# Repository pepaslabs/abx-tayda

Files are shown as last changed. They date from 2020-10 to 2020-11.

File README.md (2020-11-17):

# abx-tayda

A relay board for performing blind A/B testing of two audio sources.

This version of the board is designed around parts available from [Tayda electronics](https://www.taydaelectronics.com/).

See the thread at [diyaudio.com](https://www.diyaudio.com/forums/equipment-and-tools/361743-abx-box.html).

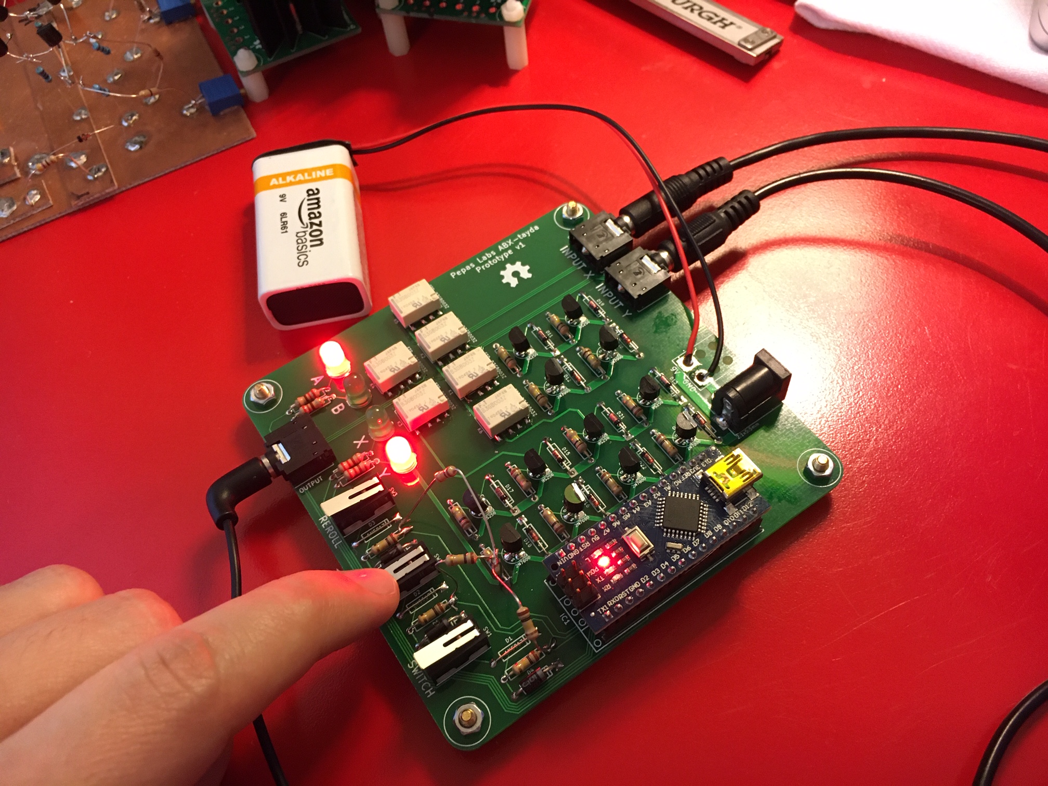
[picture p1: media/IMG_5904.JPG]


This board design is open source hardware, released under the terms of the [MIT license](https://opensource.org/licenses/MIT).  It requires an [ancient version of Kicad](https://archive.org/details/2013-kicad) (sorry, not sorry 😝).  Debian users will need to add a jessie source to install the libpng12 dependency.

## v4.1 release

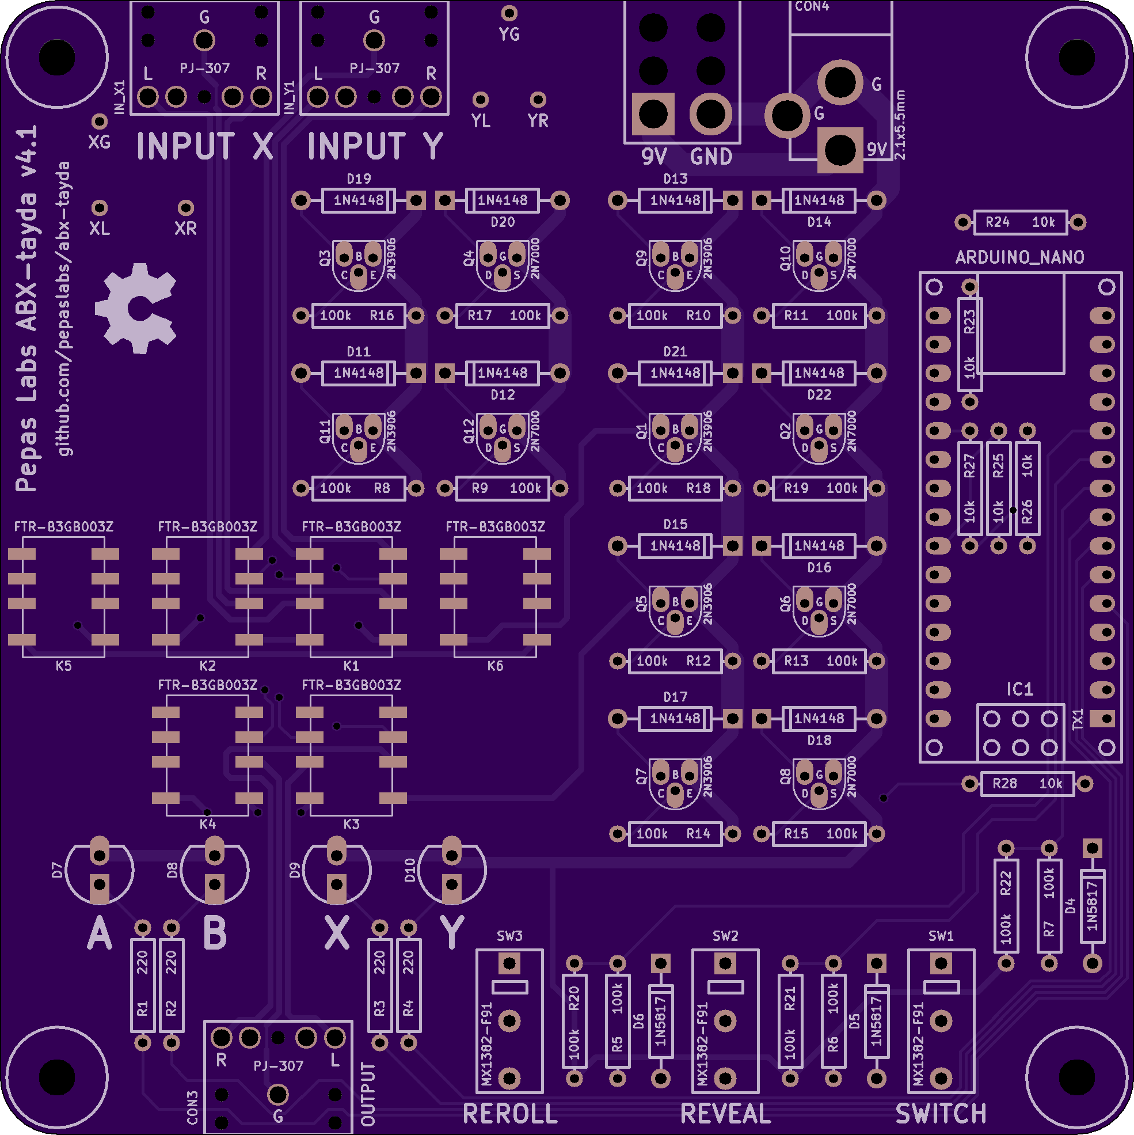
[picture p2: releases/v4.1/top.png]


[schematic](releases/v4.1/abx.pdf)

[gerbers.zip](releases/v4.1/gerbers.zip)

[firmware](https://github.com/pepaslabs/abx-tayda/blob/main/releases/v4.1/firmware/abx/abx.ino)

Changes from v4:
- Include missing base resistor R28.

### Bill of materials

- **D4-6**: three 1N5817 Schottky diodes.
  - Any diode will work, but the lower voltage drop of Schottky diodes extracts more useful life from the 9V battery.
  - [Tayda](https://www.taydaelectronics.com/1n5817-diode-schottky-1a-20v.html)
- **D7-10**: four LED's.
  - Any color.  3mm or 5mm.
  - [Tayda](https://www.taydaelectronics.com/leds/round-leds/5mm-leds/led-5mm-red.html)
- **D11-22**: twelve 1N4148 diodes.
  - Flyback diodes.  Any diode will work here.
  - [Tayda](https://www.taydaelectronics.com/1n4148-switching-signal-diode.html)
- **R1-4**: four 220R 1/4 watt resistors.
  - LED current limiting.  Tune the resistance value to get the LED brightness you prefer.
  - [Tayda](https://www.taydaelectronics.com/resistors/1-4w-metal-film-resistors/resistor-220-ohm-1-4w-1-metal-film-pkg-of-10.html)
- **R5-7,20-22**: six 100k 1/4 watt resistors.
  - Voltage dividers for Arduino inputs.  5% carbon film or 1% metal film.
  - [Tayda](https://www.taydaelectronics.com/resistors/1-4w-metal-film-resistors/10-x-resistor-100k-ohm-1-4w-1-metal-film-pkg-of-10.html)
- **R8-19**: twelve 100k 1/4 watt resistors.
  - MOSFET gate pull-up and pull-down resistors.  5% carbon film or 1% metal film.
  - [Tayda](https://www.taydaelectronics.com/resistors/1-4w-metal-film-resistors/10-x-resistor-100k-ohm-1-4w-1-metal-film-pkg-of-10.html)
- **R23-27**: six 10k 1/4 watt resistors.
  - PNP base current-limiting resistors.  5% carbon film or 1% metal film.
  - [Tayda](https://www.taydaelectronics.com/resistors/1-4w-metal-film-resistors/10-x-resistor-10k-ohm-1-4w-1-metal-film-pkg-of-10.html)
- **SW1-3**: three miniature micro switches.
  - Tayda [MX1382-F91](https://www.taydaelectronics.com/mx1382-f91-micro-switch-1p2t-1a-mx1382-f91.html)
- **Q1,3,5,7,9,11**: six 2N3906 PNP BJT transistors.
  - [Tayda](https://www.taydaelectronics.com/2n3906-general-propose-pnp-transistor.html)
  - Any TO-92 PNP transistor which can handle 100mA (with an EBC pinout) will work fine.
- **Q2,4,6,8,10,12**: six 2N7000 N-channel MOSFETs.
  - [Tayda](https://www.taydaelectronics.com/2n7000-mosfet-n-channel-60v-0-2a.html)
  - Any TO-92 N-channel MOSFET which can handle 100mA (with an SGD pinout) will work fine.
- **K1-6**: six 3V latching relays
  - Tayda [FTR-B3GB003Z](https://www.taydaelectronics.com/ftr-b3gb003z-b10-mini-relay-dpdt-3vdc-1a.html)
- **CON1-3**: three 3.5mm headphone jacks
  - Tayda [PJ-307](https://www.taydaelectronics.com/3-5mm-stereo-enclosed-socket-chassis-jack.html)
  - Digikey [SJ1-3523N](https://www.digikey.com/en/products/detail/cui-devices/SJ1-3523N/738689)
- **IC1**: one Arduino Nano board.
  - Any $5 Arduino Nano board on ebay will work fine.

Choose one:
- **CON4**: 2.1x5.5mm DC barrel jack
  - [Tayda](https://www.taydaelectronics.com/dc-power-jack-2-1mm-barrel-type-pcb-mount.html)
  - [Tayda](https://www.taydaelectronics.com/9v-9-volt-battery-clip-connector-with-barrel-jack-plug.html)
  - [Tayda](https://www.taydaelectronics.com/9v-battery-holder-with-barrel-jack-plug.html)
- **P1**: 9V battery pigtail

## v4 release

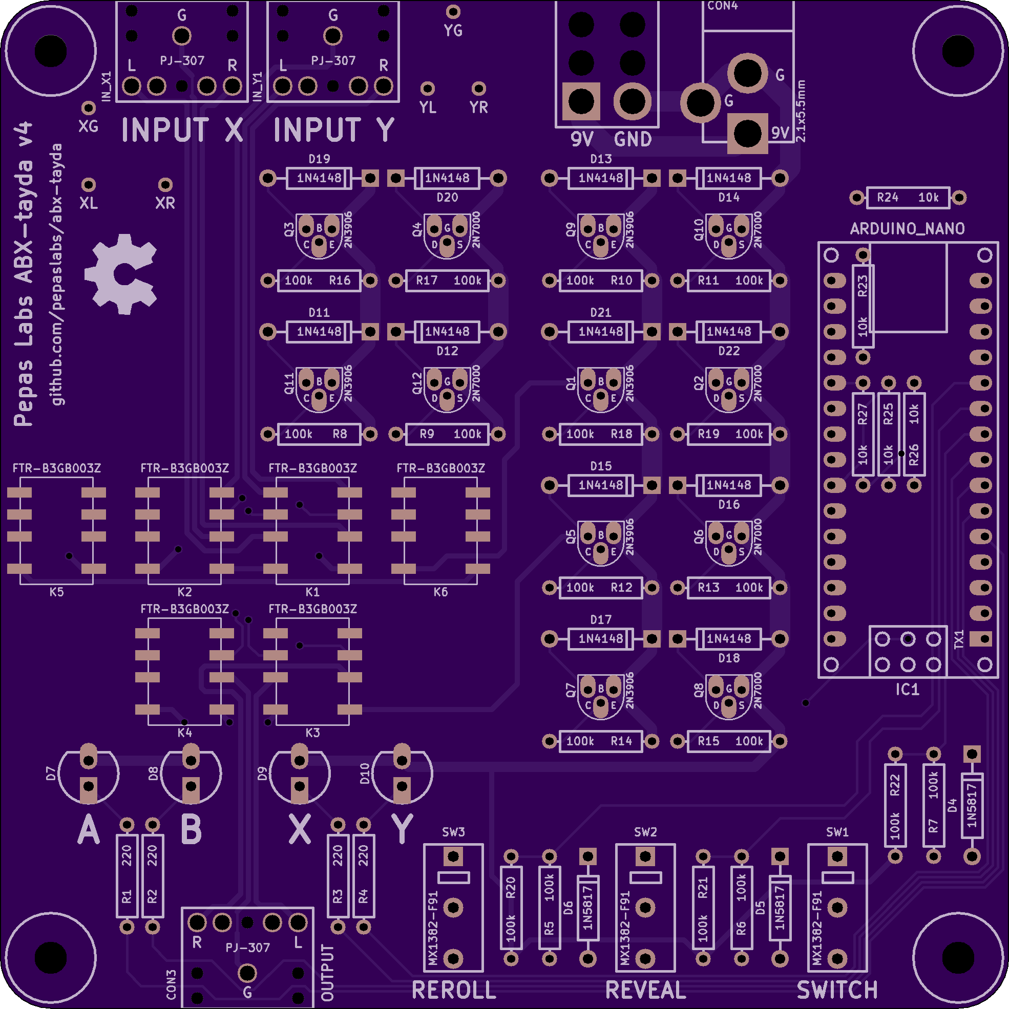
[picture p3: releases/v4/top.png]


[schematic](releases/v4/abx.pdf)

[gerbers.zip](releases/v4/gerbers.zip)

[firmware](https://github.com/pepaslabs/abx-tayda/blob/main/releases/v4/firmware/abx/abx.ino)

Changes from v3:
- Use 2N3906 PNP BJT's which are cheaper than BS250 P-channel MOSFETs (and are available from tayda)
- Use wider traces for the signal path.

## v3 release

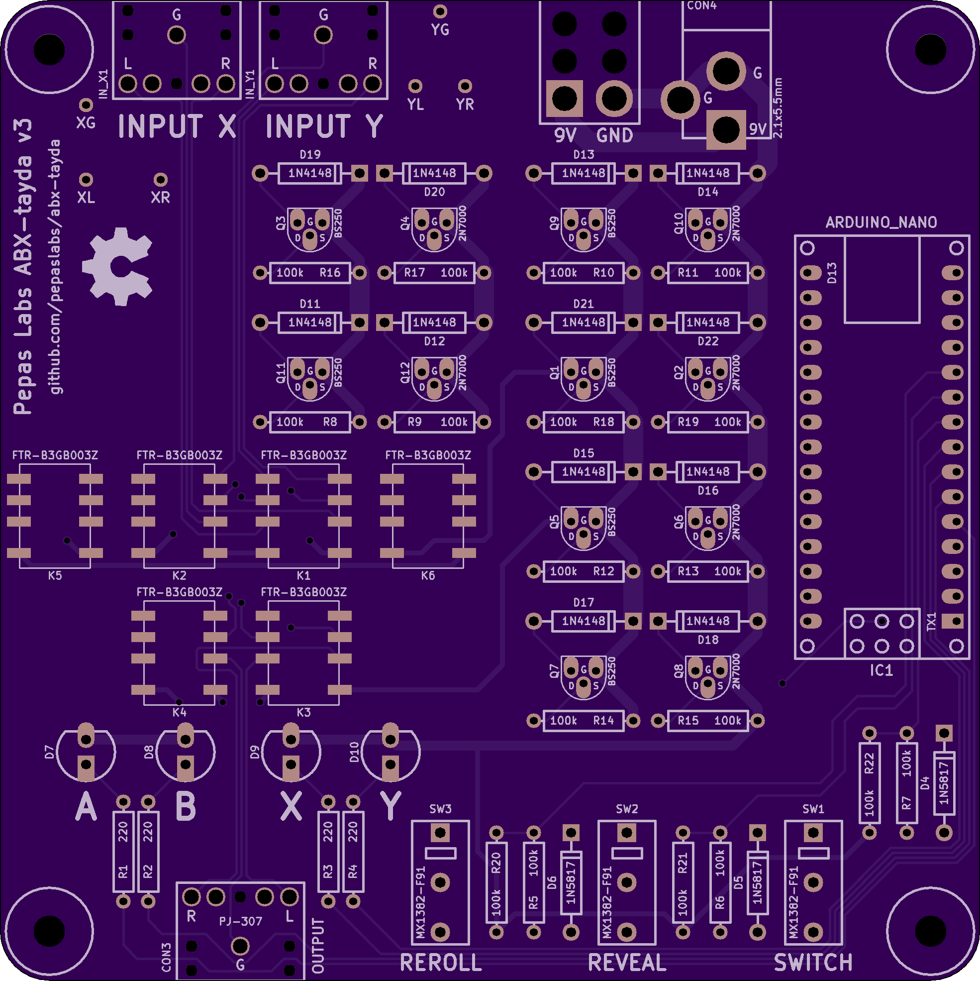
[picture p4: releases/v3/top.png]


[schematic](releases/v3/abx.pdf)

[gerbers.zip](releases/v3/gerbers.zip)

[firmware](https://github.com/pepaslabs/abx-tayda/blob/main/releases/v3/firmware/abx/abx.ino)

Changes from v2:
- Add test points to input X and Y for volume matching convenience.
- Use pins RX0, TX1 instead of A6, A7 (which cannot be used a digital outputs).

## v2 release

This release fixes a couple of bugs from v1:
- Replaced the 100k input resistors with proper voltage dividers.
- Fixed the silkscreen outline of the relays.

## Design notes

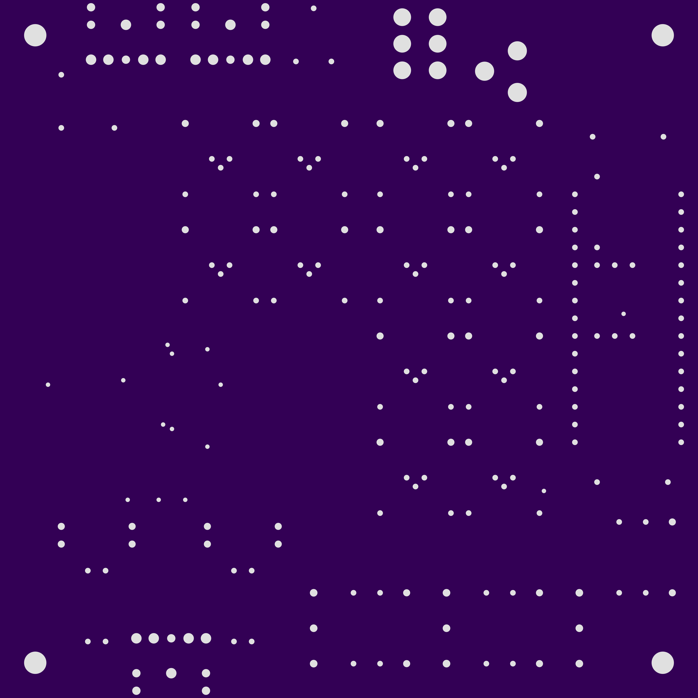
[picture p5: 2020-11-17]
releases/v4.1/drills.png

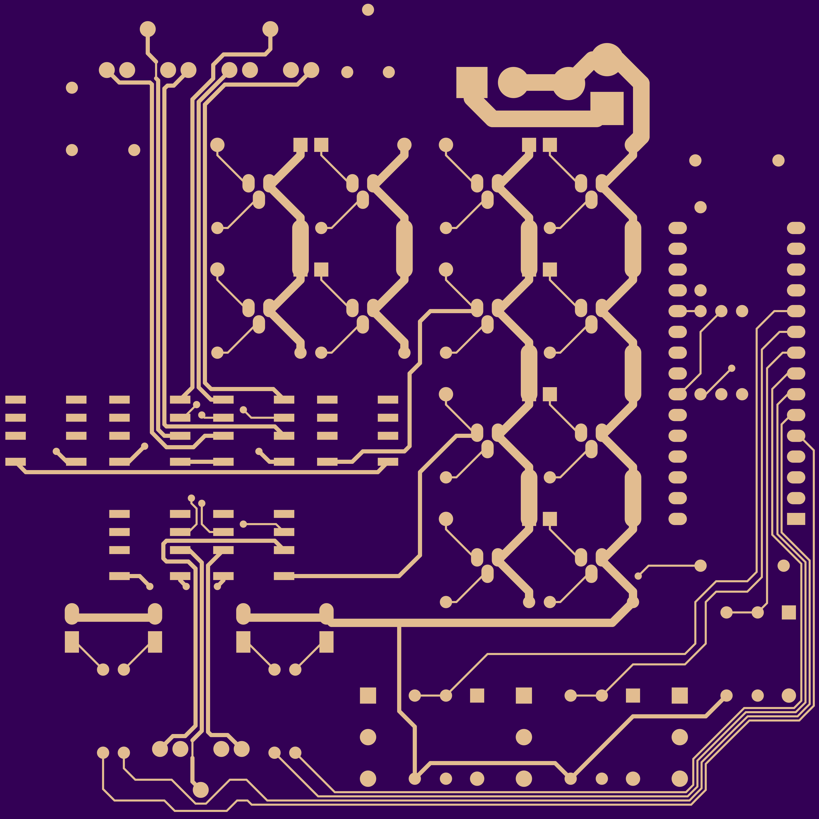
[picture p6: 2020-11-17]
releases/v4.1/top-copper.png

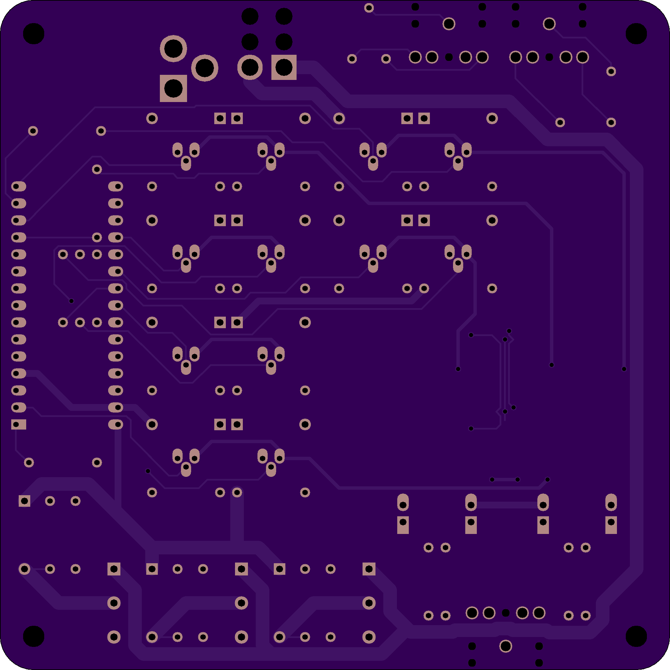
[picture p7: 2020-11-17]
releases/v4.1/bottom.png

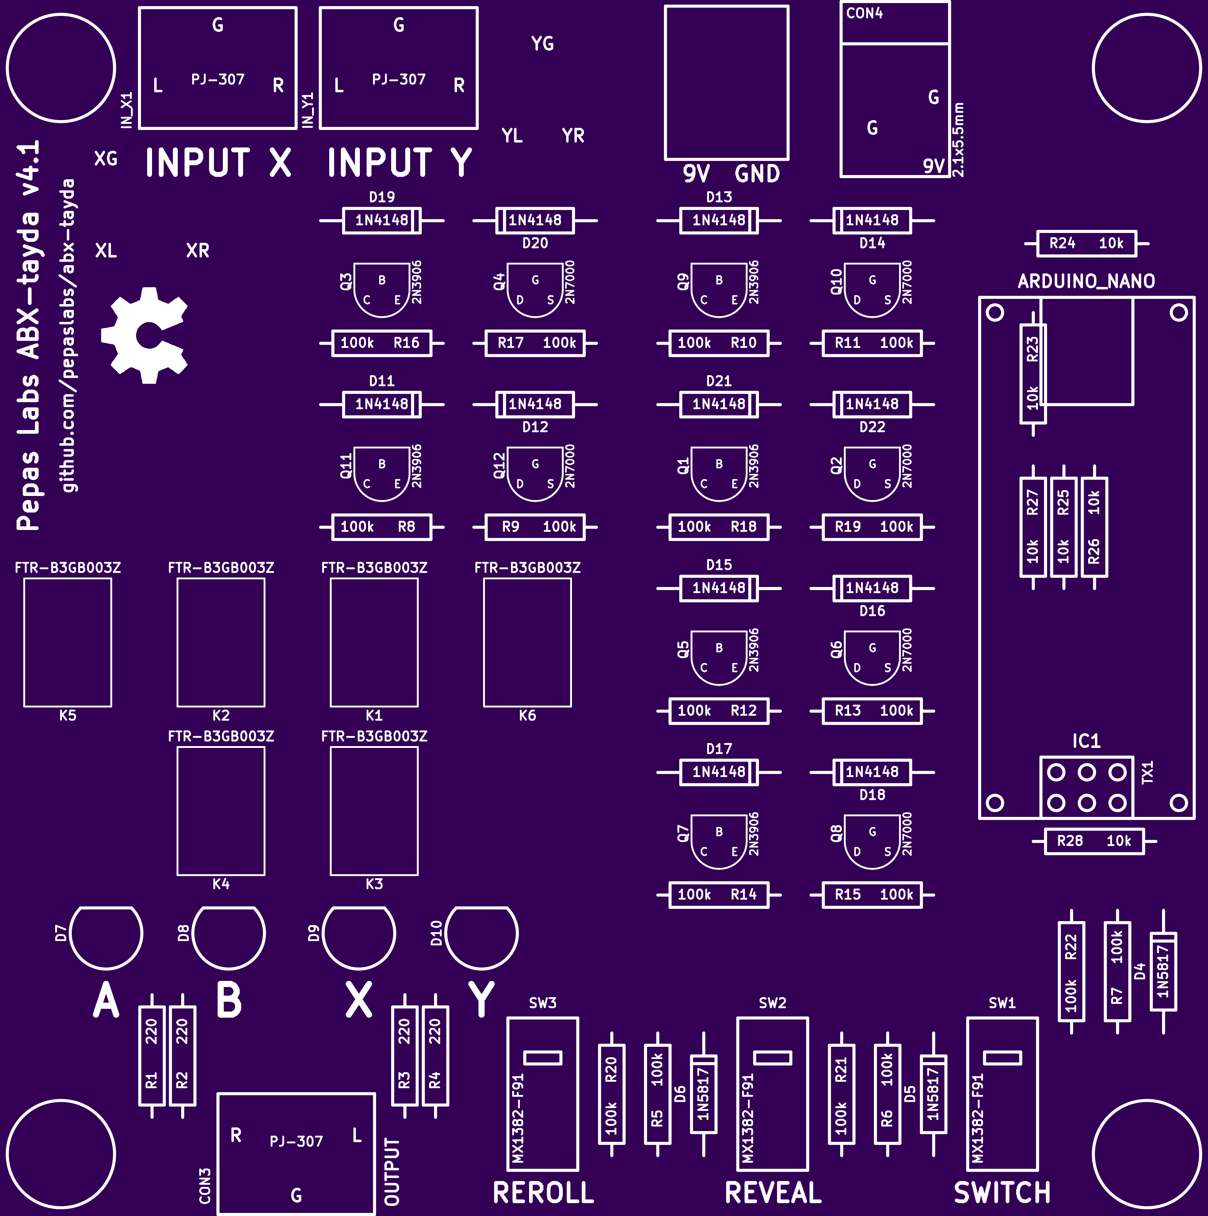
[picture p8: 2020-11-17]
releases/v4.1/top-silk.png

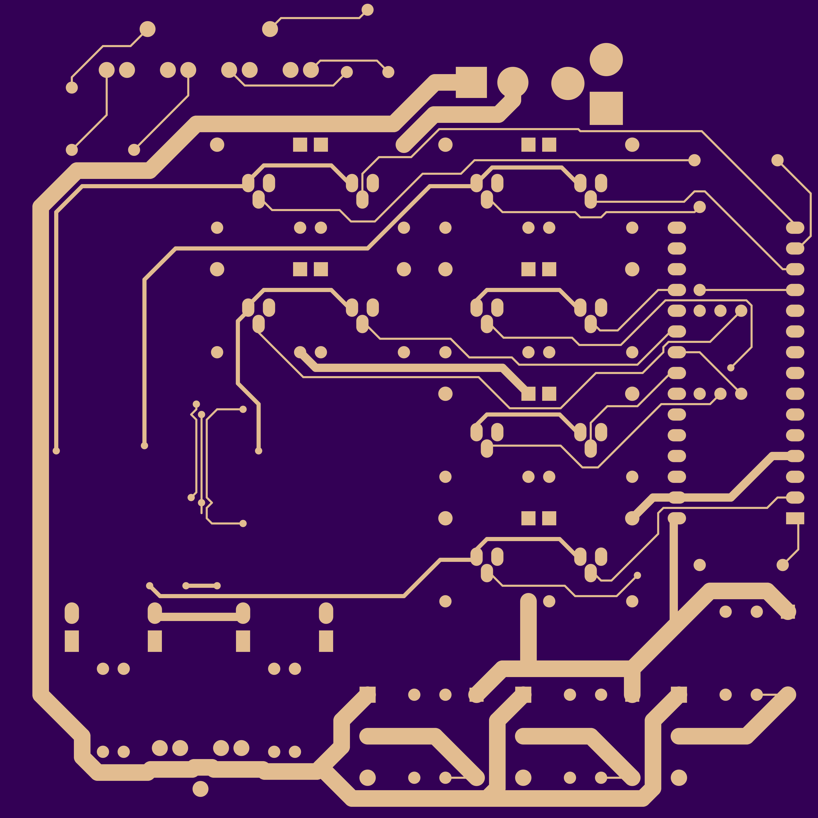
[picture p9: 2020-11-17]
releases/v4.1/bottom-copper.png

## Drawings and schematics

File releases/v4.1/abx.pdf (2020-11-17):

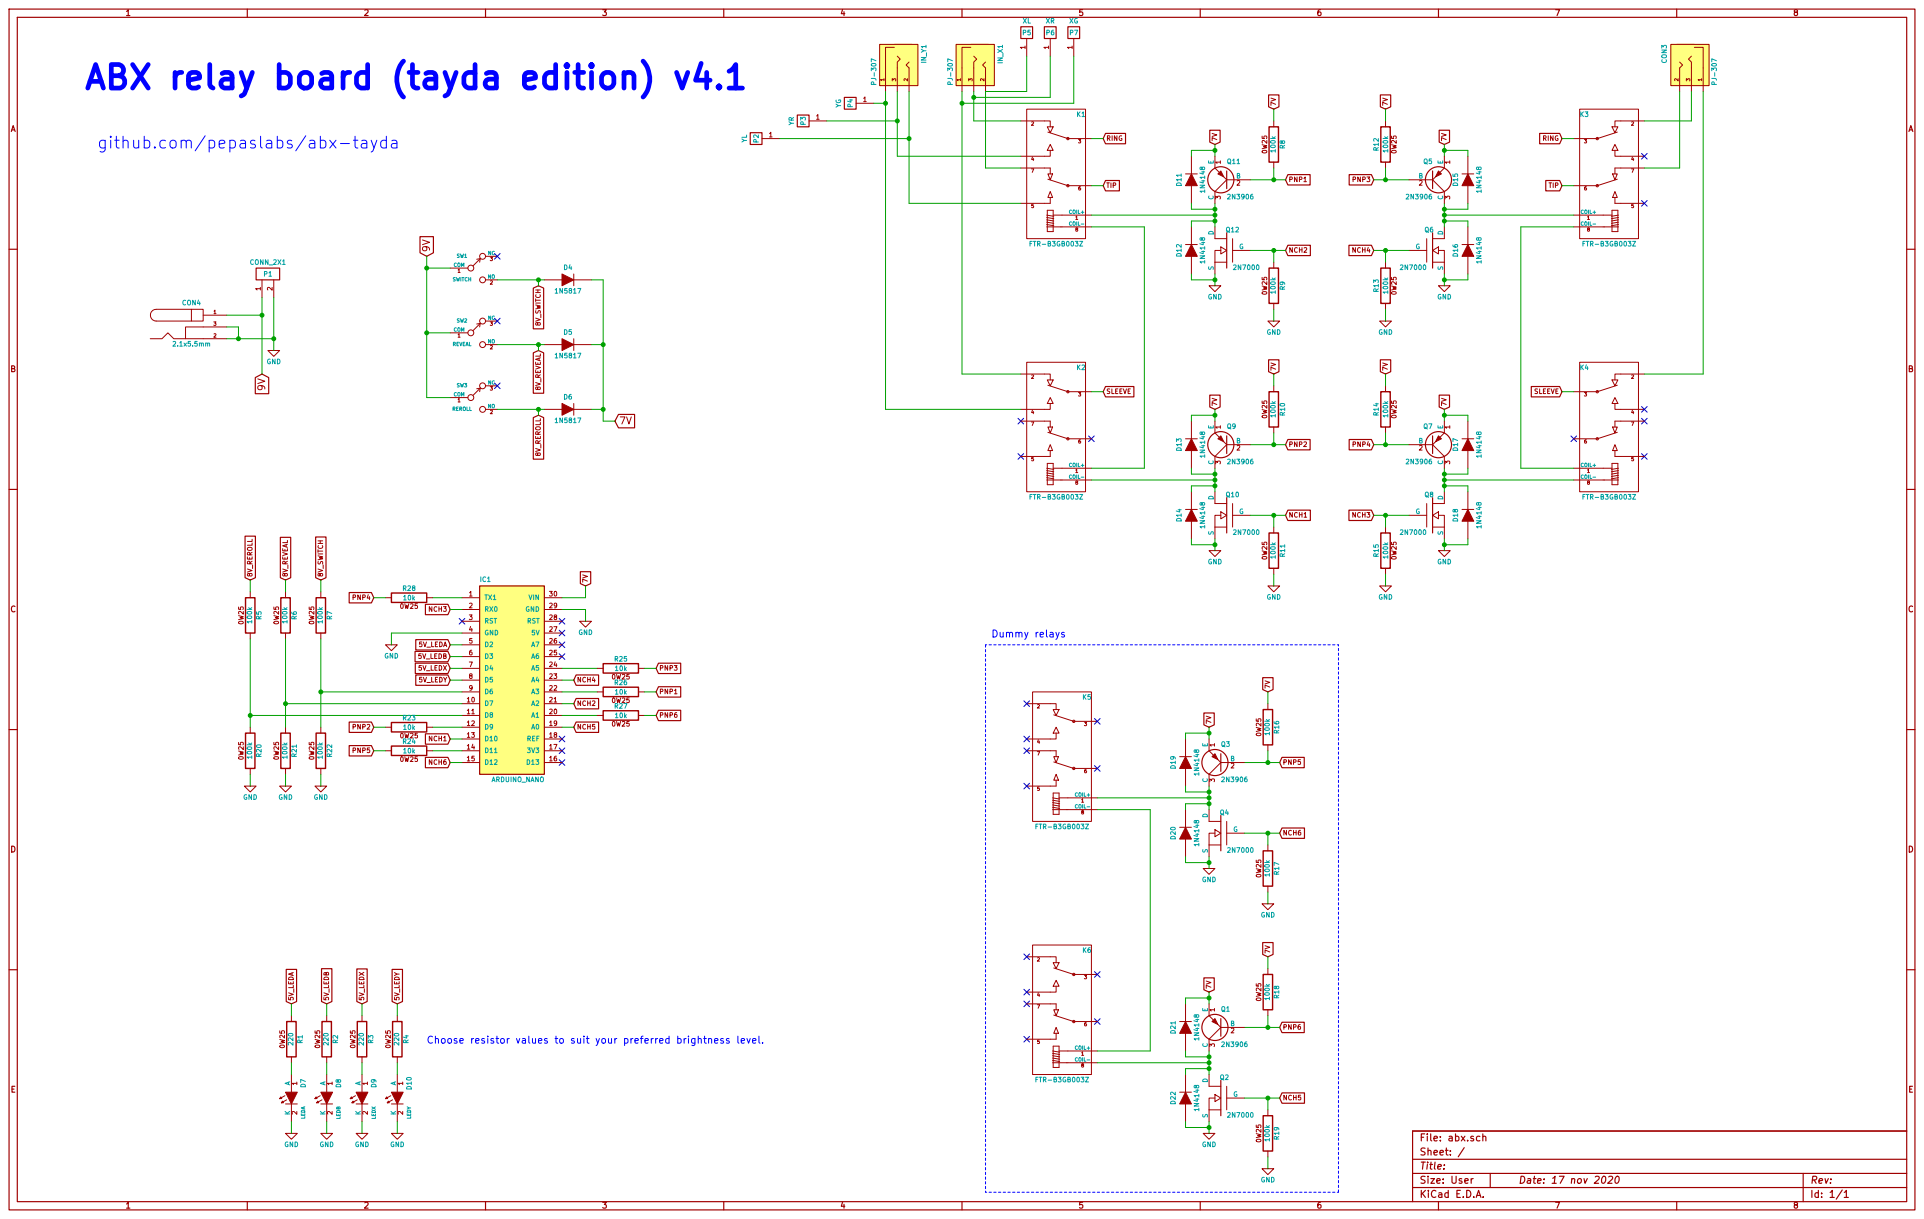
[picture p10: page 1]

github.com/pepaslabs/abx-tayda

Choose resistor values to suit your preferred brightness level.

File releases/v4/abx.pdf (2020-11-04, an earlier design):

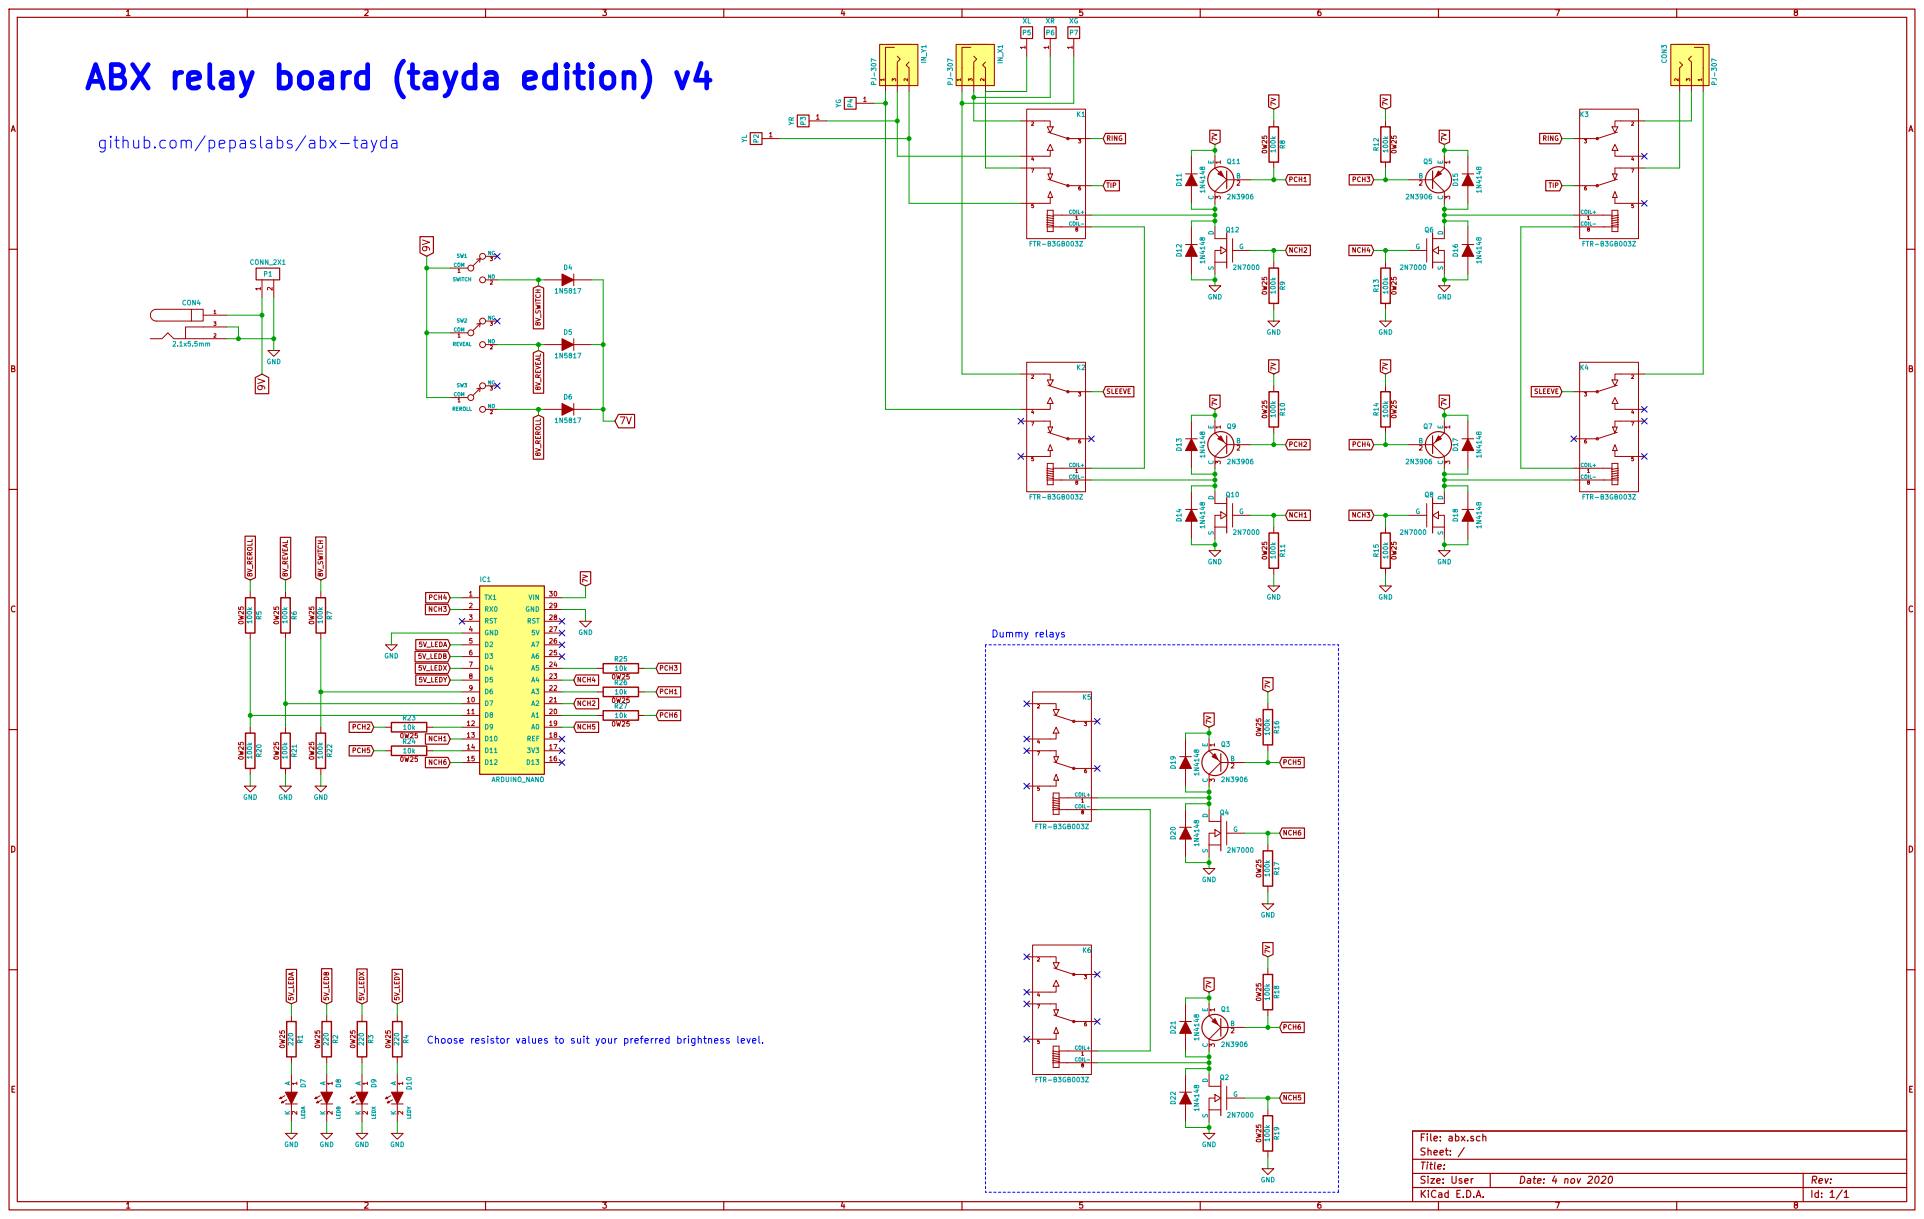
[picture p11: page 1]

github.com/pepaslabs/abx-tayda

Choose resistor values to suit your preferred brightness level.

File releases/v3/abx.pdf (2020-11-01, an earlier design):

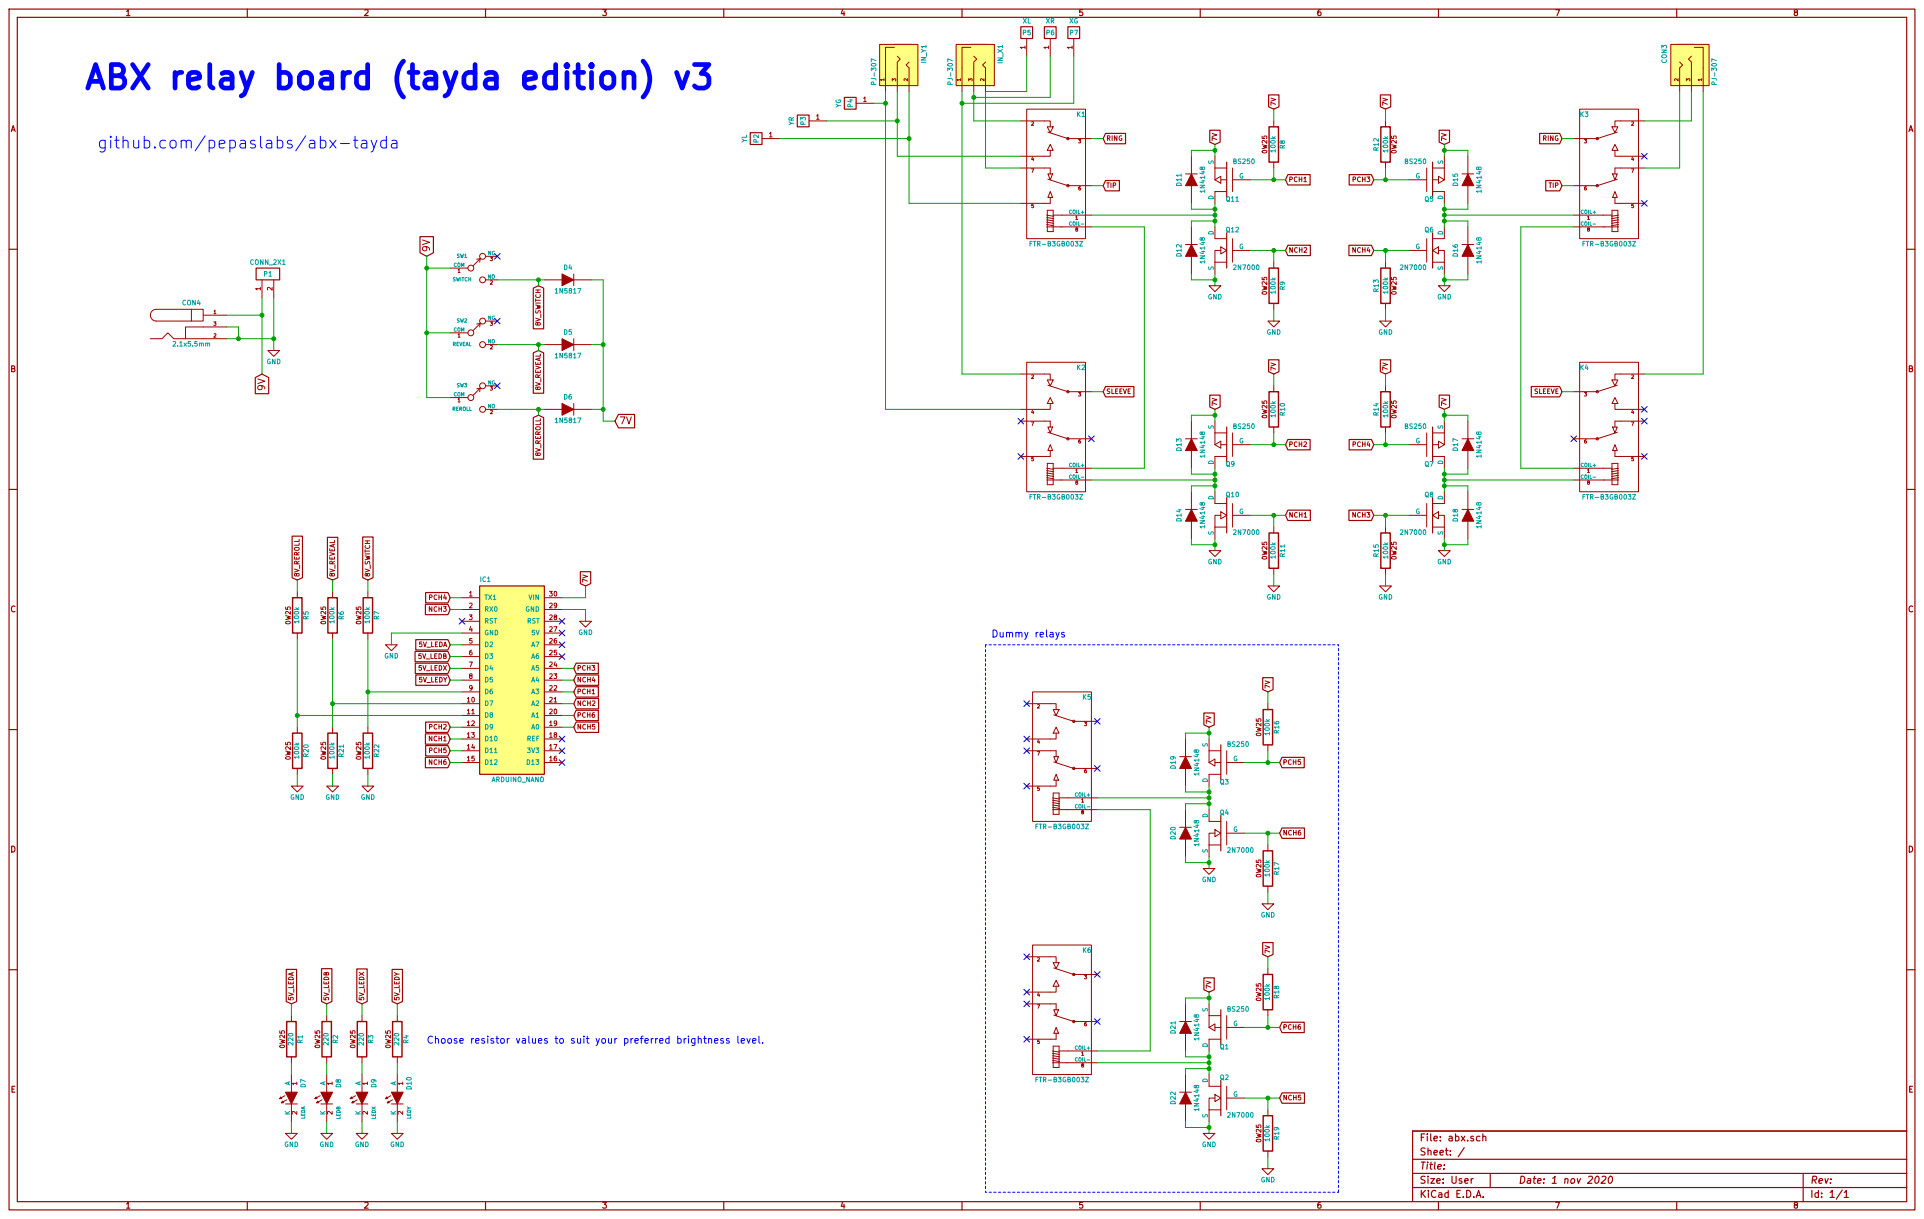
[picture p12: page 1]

github.com/pepaslabs/abx-tayda

Choose resistor values to suit your preferred brightness level.

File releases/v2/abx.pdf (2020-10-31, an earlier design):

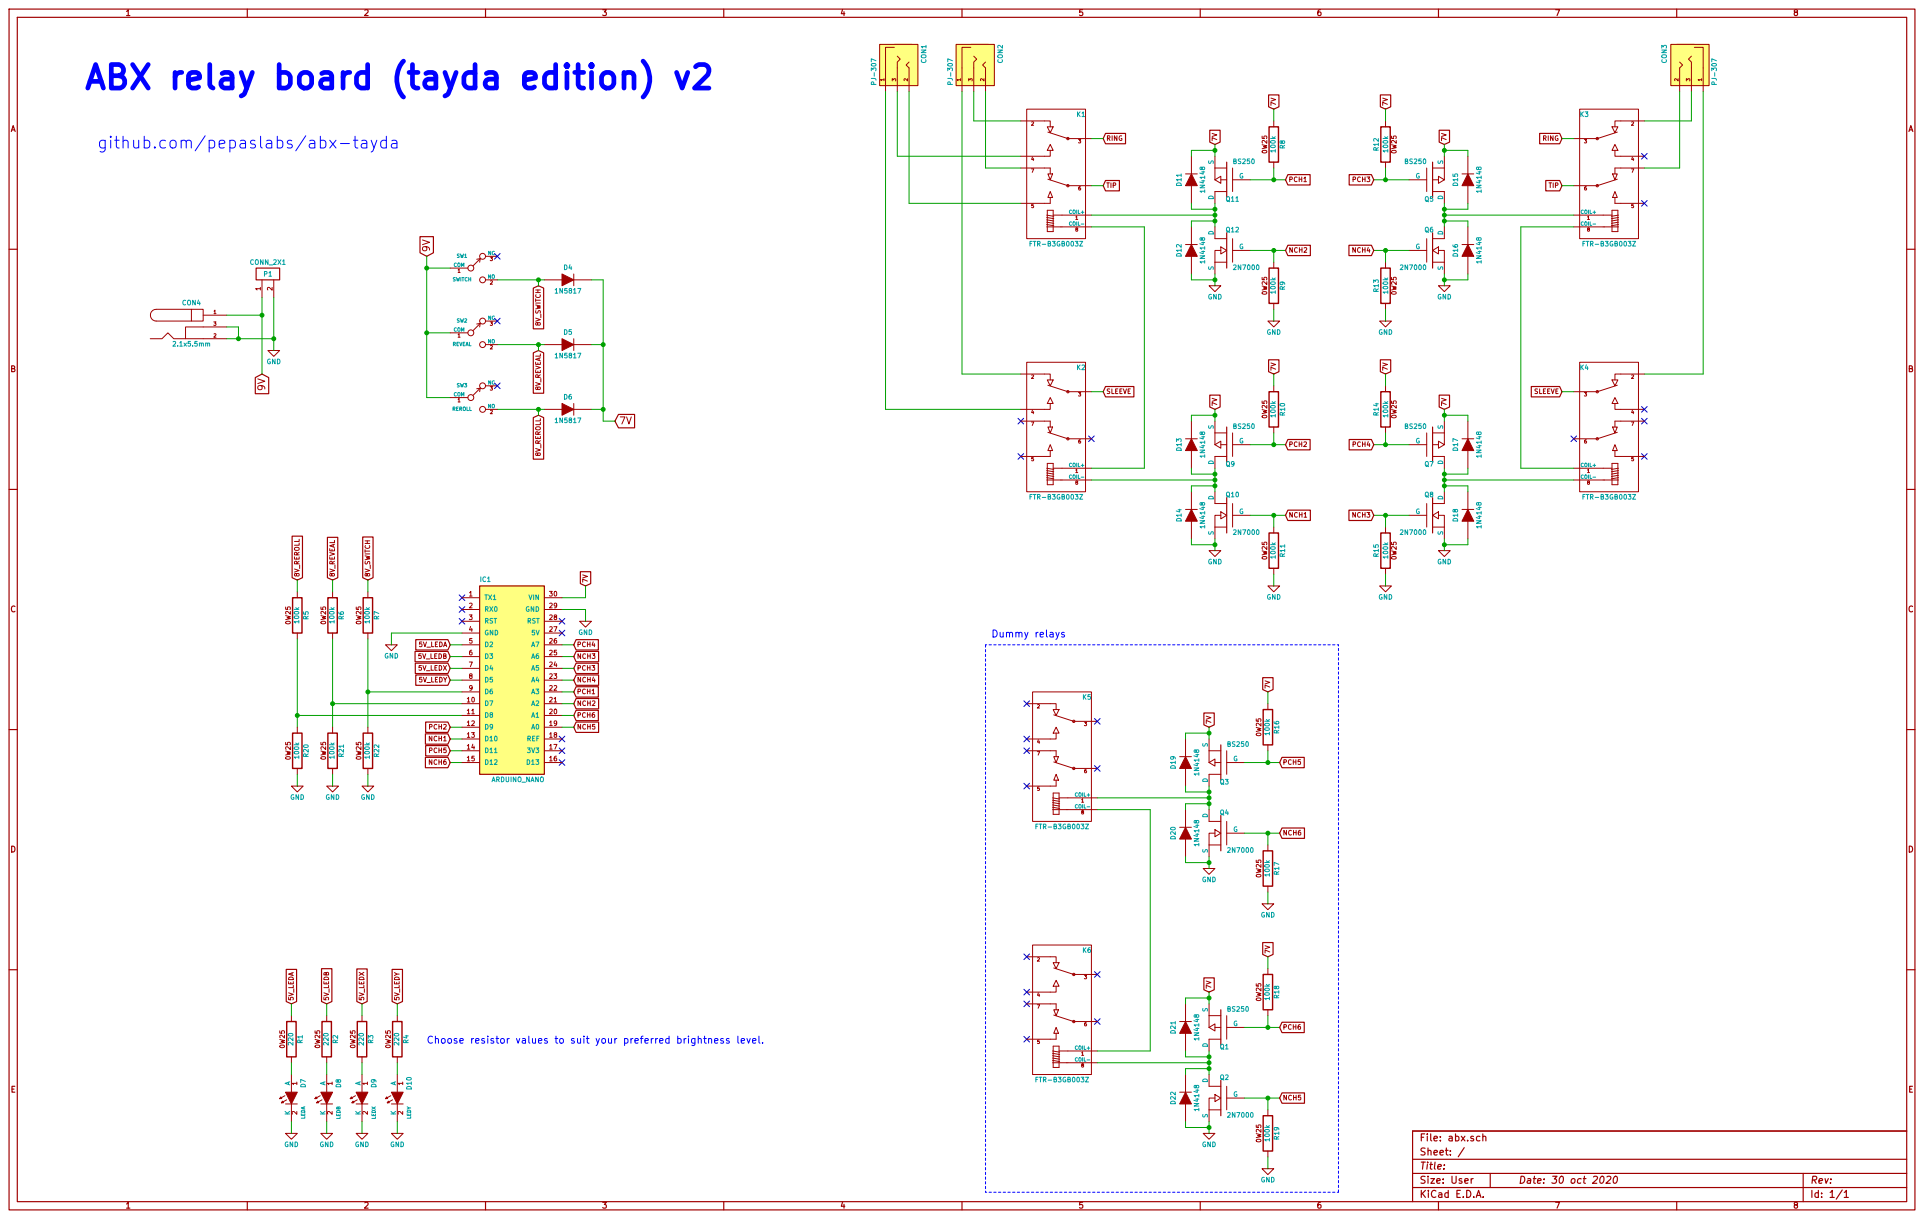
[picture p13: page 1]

github.com/pepaslabs/abx-tayda

Choose resistor values to suit your preferred brightness level.

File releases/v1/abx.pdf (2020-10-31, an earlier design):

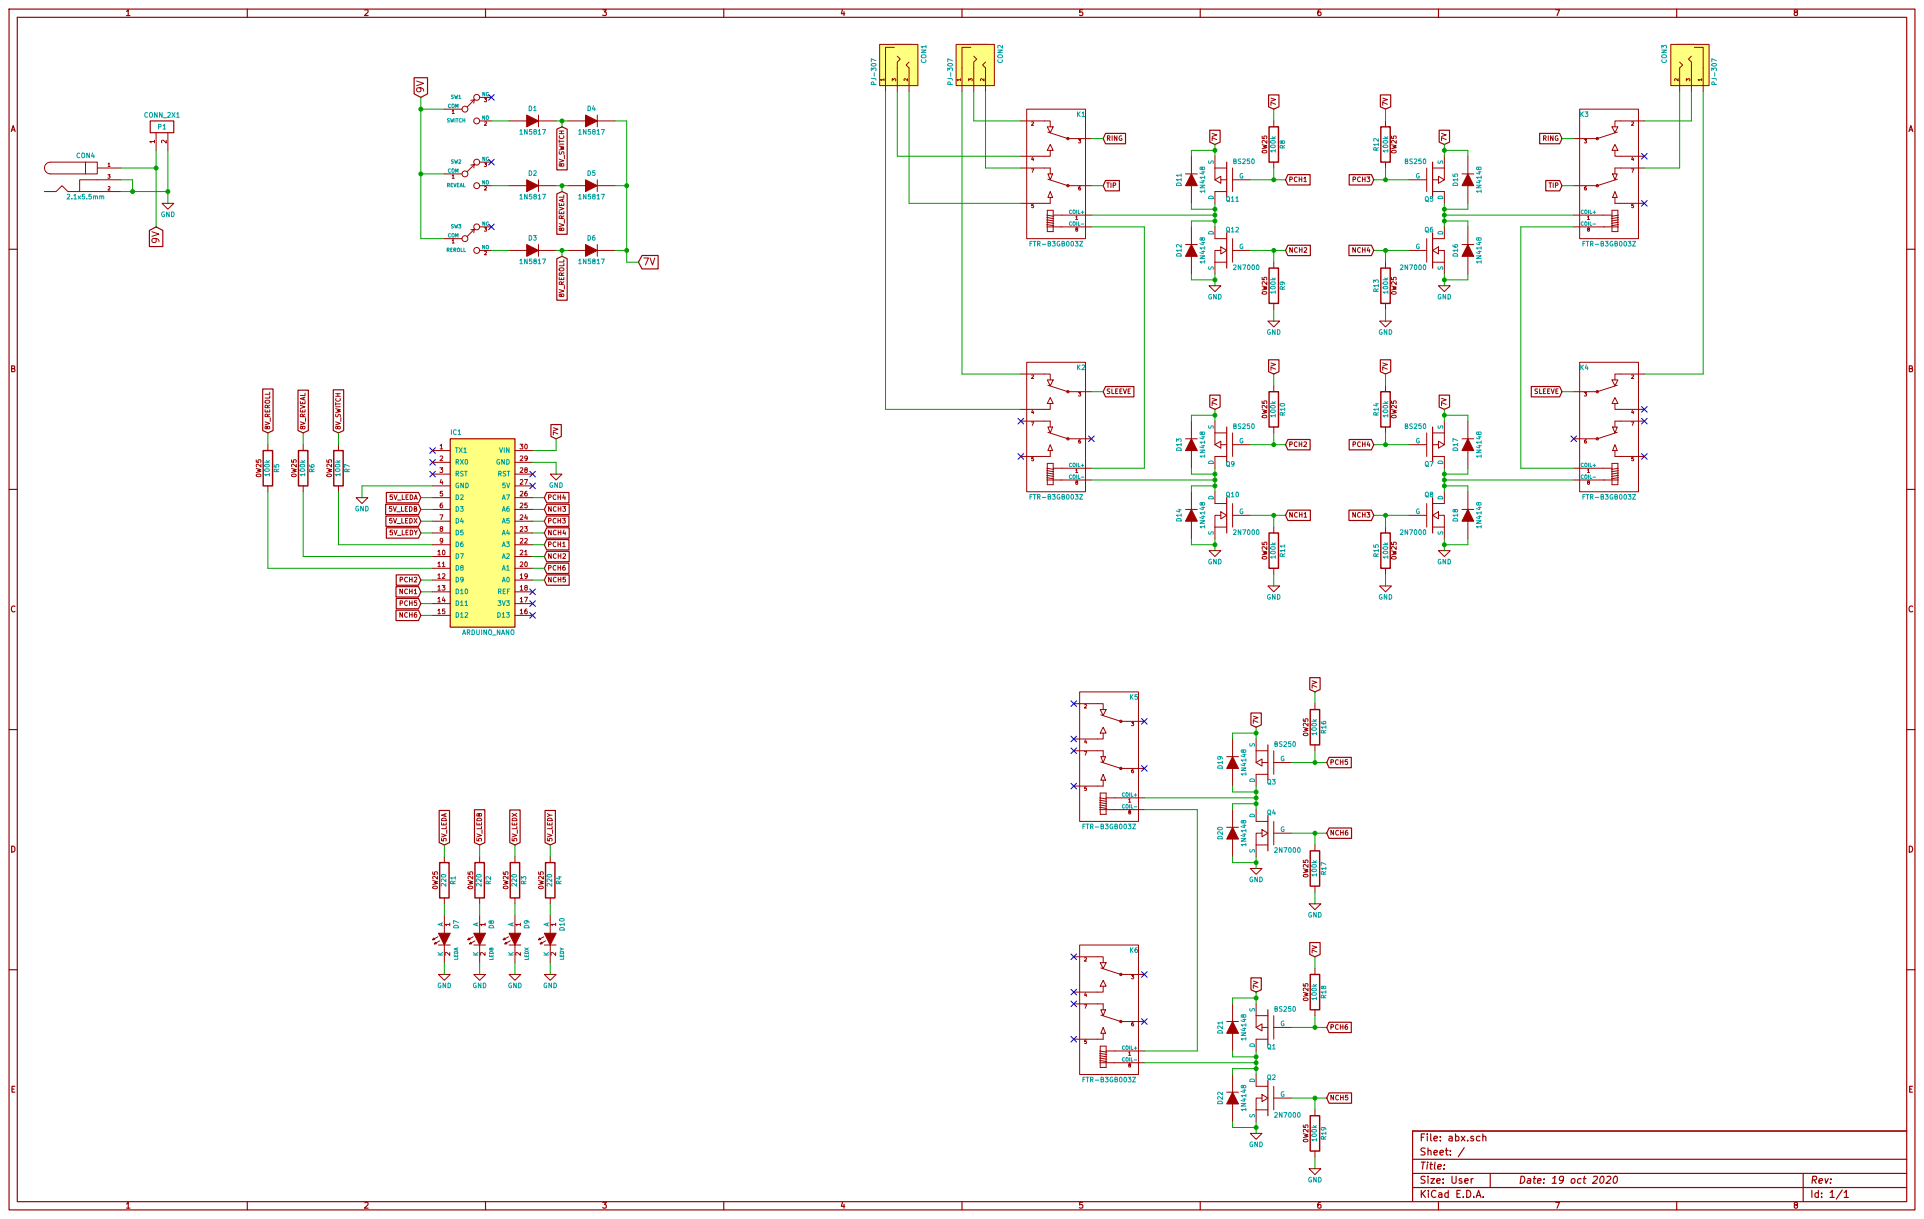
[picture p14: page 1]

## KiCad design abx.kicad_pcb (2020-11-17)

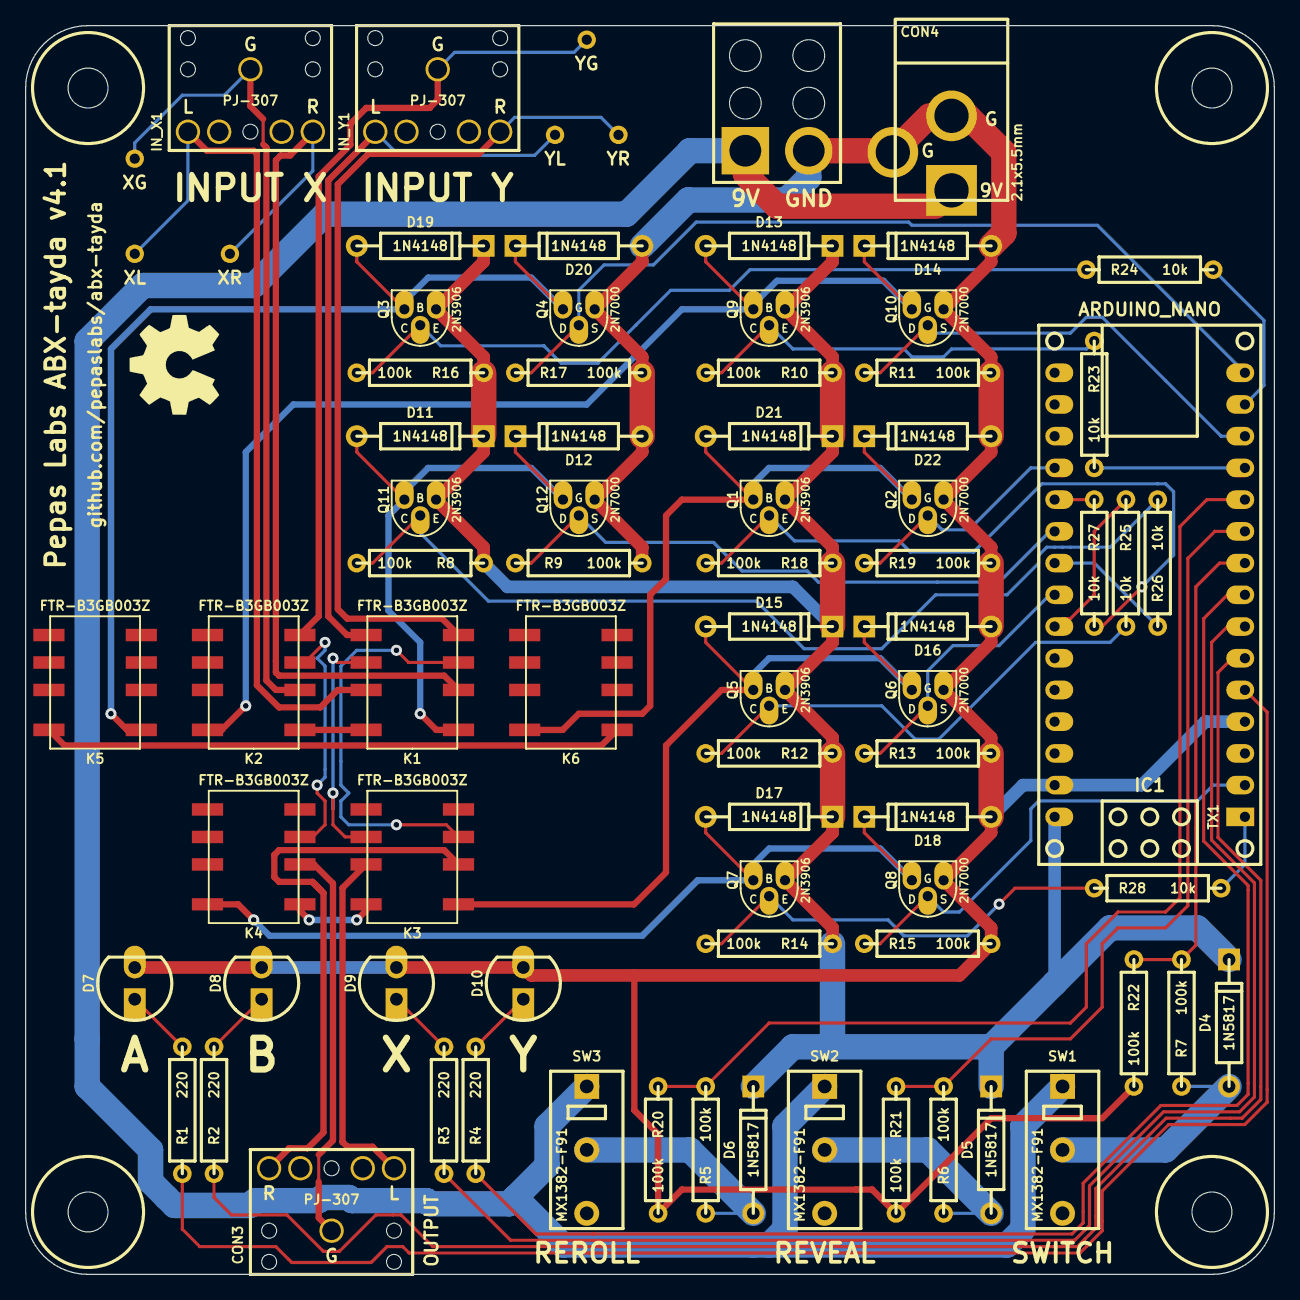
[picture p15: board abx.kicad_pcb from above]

Board: 2 copper layers, 100.0 x 100.0 mm, 84 parts (0 on the bottom side), 56 nets.

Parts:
CON3: PJ-307; SJ1-3523N
CON4: 2.1x5.5mm; BARREL_JACK_21x55
D4, D5, D6: 1N5817; DIODE_1A_069A_04_PL
D7: LEDA; LED_5MM
D8: LEDB; LED_5MM
D9: LEDX; LED_5MM
D10: LEDY; LED_5MM
D11, D12, D13, D14, D15, D16, D17, D18, D19, D20, D21, D22: 1N4148; DIODE_1A_069A_04_PL
H***: Val**; hole_M3_NPTH
H***#2, H***#3, H***#4: Val**; hole_M3_NPTH
IC1: ARDUINO_NANO; ARDUINO_NANO_PL
IN_X1: PJ-307; SJ1-3523N
IN_Y1: PJ-307; SJ1-3523N
K1, K2, K3, K4, K5, K6: FTR-B3GB003Z; FTR-B3G
P1: CONN_2X1; PIGTAIL2
P2: YL; 1pin_032_058
P3: YR; 1pin_032_058
P4: YG; 1pin_032_058
P5: XL; 1pin_032_058
P6: XR; 1pin_032_058
P7: XG; 1pin_032_058
Q1, Q3, Q5, Q7, Q9, Q11: 2N3906; TO-92_Q_EBC_059Bo_PL
Q2, Q4, Q6, Q8, Q10, Q12: 2N7000; TO-92_Q_SGD_059Bo_PL
R1, R2, R3, R4: 220; R_AXIAL_0W25_059A_PL
R5, R6, R7, R8, R9, R10, R11, R12, R13, R14, R15, R16, R17, R18, R19, R20, R21, R22: 100k; R_AXIAL_0W25_059A_PL
R23, R24, R25, R26, R27, R28: 10k; R_AXIAL_0W25_059A_PL
SW1: SWITCH; MX1382-F91
SW2: REVEAL; MX1382-F91
SW3: REROLL; MX1382-F91

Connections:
5V_LEDA: IC1.5, R1.1
5V_LEDB: IC1.6, R2.1
5V_LEDX: IC1.7, R3.1
5V_LEDY: IC1.8, R4.1
7V: D4.2, D5.2, D6.2, D11.2, D13.2, D15.2, D17.2, D19.2, D21.2, IC1.30, Q1.1, Q3.1, Q5.1, Q7.1, Q9.1, Q11.1, R8.1, R10.1, R12.1, R14.1, R16.1, R18.1
8V_REROLL: D6.1, R5.1, SW3.2
8V_REVEAL: D5.1, R6.1, SW2.2
8V_SWITCH: D4.1, R7.1, SW1.2
9V: CON4.1, P1.1, SW1.1, SW2.1, SW3.1
GND: CON4.2, CON4.3, D7.2, D8.2, D9.2, D10.2, D12.1, D14.1, D16.1, D18.1, D20.1, D22.1, IC1.4, IC1.29, P1.2, Q2.1, Q4.1, Q6.1, Q8.1, Q10.1, Q12.1, R9.2, R11.2, R13.2, R15.2, R17.2, R19.2, R20.2, R21.2, R22.2
unnamed: K3.8, K4.1
unnamed: CON3.3, K3.2
unnamed: CON3.1, K4.2
unnamed: IC1.24, R25.1
unnamed: K5.8, K6.1
unnamed: D9.1, R3.2
unnamed: D8.1, R2.2
unnamed: D7.1, R1.2
unnamed: D10.1, R4.2
unnamed: IN_Y1.3, K1.4, P3.1
unnamed: IN_Y1.1, K2.4, P4.1
unnamed: IC1.9, R7.2, R22.1
unnamed: K1.8, K2.1
unnamed: IC1.10, R6.2, R21.1
unnamed: IC1.14, R24.2
unnamed: IC1.12, R23.2
unnamed: IC1.11, R5.2, R20.1
unnamed: IC1.1, R28.2
unnamed: IN_X1.3, K1.2, P6.1
unnamed: IN_X1.2, K1.7, P5.1
unnamed: IN_Y1.2, K1.5, P2.1
unnamed: CON3.2, K3.7
unnamed: IN_X1.1, K2.2, P7.1
unnamed: IC1.22, R26.1
unnamed: IC1.20, R27.1
unnamed: D15.1, D16.2, K3.1, Q5.3, Q6.3
unnamed: D19.1, D20.2, K5.1, Q3.3, Q4.3
unnamed: D21.1, D22.2, K6.8, Q1.3, Q2.3
unnamed: D11.1, D12.2, K1.1, Q11.3, Q12.3
unnamed: D17.1, D18.2, K4.8, Q7.3, Q8.3
unnamed: D13.1, D14.2, K2.8, Q9.3, Q10.3
NCH1: IC1.13, Q10.2, R11.1
NCH2: IC1.21, Q12.2, R9.1
NCH3: IC1.2, Q8.2, R15.1
NCH4: IC1.23, Q6.2, R13.1
NCH5: IC1.19, Q2.2, R19.1
NCH6: IC1.15, Q4.2, R17.1
PNP1: Q11.2, R8.2, R26.2
PNP2: Q9.2, R10.2, R23.1
PNP3: Q5.2, R12.2, R25.2
PNP4: Q7.2, R14.2, R28.1
PNP5: Q3.2, R16.2, R24.1
PNP6: Q1.2, R18.2, R27.2
RING: K1.3, K3.3
SLEEVE: K2.3, K4.3
TIP: K1.6, K3.6

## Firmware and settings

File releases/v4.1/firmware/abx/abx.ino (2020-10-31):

// ABX switch box (tayda version).
// Copyright 2020 Jason Pepas
// Released under the terms of the MIT license.
// See https://opensource.org/licenses/MIT

// Forum thread:
// https://www.diyaudio.com/forums/equipment-and-tools/361743-abx-box.html


#include <EEPROM.h>


// Pin mapping:

#define LED_A 2
#define LED_B 3
#define LED_X 4
#define LED_Y 5

#define PCH1 A3
#define NCH1 10
#define PCH2 9
#define NCH2 A2
#define PCH3 A5
#define NCH3 0
#define PCH4 1
#define NCH4 A4
#define PCH5 11
#define NCH5 A0
#define PCH6 A1
#define NCH6 12

#define MODE_PIN_REROLL 8
#define MODE_PIN_REVEAL 7
#define MODE_PIN_SWITCH 6


// Misc. constants:

#define MAPPING_A_IS_X 101
#define MAPPING_A_IS_Y 102
#define MAPPING_B_IS_X 102
#define MAPPING_B_IS_Y 101

#define POSITION_X 103
#define POSITION_Y 104

#define RELAY_DURATION 4


// Global variables:

byte g_eeprom_initialized;
byte g_random_seed;
byte g_random_seq;
byte g_abxy_mapping;
byte g_input_position;
byte g_dummy_position;


// EEPROM addresses

#define G_EEPROM_INITIALIZED_ADDR 0
#define G_RANDOM_SEED_ADDR 1
#define G_RANDOM_SEQ_ADDR 2
#define G_ABXY_MAPPING_ADDR 3
#define G_INPUT_POSITION_ADDR 4
#define G_DUMMY_POSITION_ADDR 5


// Misc. functions:

void panic() {
    pinMode(LED_A, OUTPUT);
    pinMode(LED_B, OUTPUT);
    while (true) {
        digitalWrite(LED_A, HIGH);
        digitalWrite(LED_B, HIGH);
    }
}


// EEPROM functions

void load_globals_from_eeprom() {
    g_eeprom_initialized = EEPROM.read(G_EEPROM_INITIALIZED_ADDR);
    if (g_eeprom_initialized != 42) {
        // this is the first time we have ever been run.  initialize all state.
        EEPROM.write(G_EEPROM_INITIALIZED_ADDR, 42);
        EEPROM.write(G_RANDOM_SEED_ADDR, 0);
        EEPROM.write(G_RANDOM_SEQ_ADDR, 0);
        EEPROM.write(G_ABXY_MAPPING_ADDR, MAPPING_A_IS_X);
        EEPROM.write(G_INPUT_POSITION_ADDR, POSITION_X);
        EEPROM.write(G_DUMMY_POSITION_ADDR, POSITION_X);
        disconnect_output_relays();
        set_input_relays_to_x();
        set_dummy_relays_to_x();
        connect_output_relays();
    }

    g_random_seed = EEPROM.read(G_RANDOM_SEED_ADDR);
    g_random_seq = EEPROM.read(G_RANDOM_SEQ_ADDR);
    g_abxy_mapping = EEPROM.read(G_ABXY_MAPPING_ADDR);
    g_input_position = EEPROM.read(G_INPUT_POSITION_ADDR);
    g_dummy_position = EEPROM.read(G_DUMMY_POSITION_ADDR);
}

void store_globals_in_eeprom() {
    EEPROM.write(G_RANDOM_SEED_ADDR, g_random_seed);
    EEPROM.write(G_RANDOM_SEQ_ADDR, g_random_seq);
    EEPROM.write(G_ABXY_MAPPING_ADDR, g_abxy_mapping);
    EEPROM.write(G_INPUT_POSITION_ADDR, g_input_position);
    EEPROM.write(G_DUMMY_POSITION_ADDR, g_dummy_position);
}


// LED functions:

void turn_on_LED(int led) {
    pinMode(led, OUTPUT);
    digitalWrite(led, HIGH);
}

void turn_off_LED(int led) {
    pinMode(led, INPUT);
}


// Relay functions:

void set_input_relays_to_x() {
    pinMode(PCH1, OUTPUT);
    digitalWrite(PCH1, LOW);
    pinMode(NCH1, OUTPUT);
    digitalWrite(NCH1, HIGH);
    delay(RELAY_DURATION);
    pinMode(PCH1, INPUT);
    pinMode(NCH1, INPUT);
    delay(1);
    g_input_position = POSITION_X;
}

void set_input_relays_to_y() {
    pinMode(PCH2, OUTPUT);
    digitalWrite(PCH2, LOW);
    pinMode(NCH2, OUTPUT);
    digitalWrite(NCH2, HIGH);
    delay(RELAY_DURATION);
    pinMode(PCH2, INPUT);
    pinMode(NCH2, INPUT);
    delay(1);
    g_input_position = POSITION_Y;
}

void set_dummy_relays_to_x() {
    pinMode(PCH5, OUTPUT);
    digitalWrite(PCH5, LOW);
    pinMode(NCH5, OUTPUT);
    digitalWrite(NCH5, HIGH);
    delay(RELAY_DURATION);
    pinMode(PCH5, INPUT);
    pinMode(NCH5, INPUT);
    delay(1);
    g_dummy_position = POSITION_X;
}

void set_dummy_relays_to_y() {
    pinMode(PCH6, OUTPUT);
    digitalWrite(PCH6, LOW);
    pinMode(NCH6, OUTPUT);
    digitalWrite(NCH6, HIGH);
    delay(RELAY_DURATION);
    pinMode(PCH6, INPUT);
    pinMode(NCH6, INPUT);
    delay(1);
    g_dummy_position = POSITION_Y;
}

void toggle_input_relays() {
    if (g_input_position == POSITION_X) {
        set_input_relays_to_y();
    } else if (g_input_position == POSITION_Y) {
        set_input_relays_to_x();
    } else {
        panic();
    }
}

void toggle_dummy_relays() {
    if (g_dummy_position == POSITION_X) {
        set_dummy_relays_to_y();
    } else if (g_dummy_position == POSITION_Y) {
        set_dummy_relays_to_x();
    } else {
        panic();
    }
}

void connect_output_relays() {
    pinMode(PCH3, OUTPUT);
    digitalWrite(PCH3, LOW);
    pinMode(NCH3, OUTPUT);
    digitalWrite(NCH3, HIGH);
    delay(RELAY_DURATION);
    pinMode(PCH3, INPUT);
    pinMode(NCH3, INPUT);
    delay(1);
}

void disconnect_output_relays() {
    pinMode(PCH4, OUTPUT);
    digitalWrite(PCH4, LOW);
    pinMode(NCH4, OUTPUT);
    digitalWrite(NCH4, HIGH);
    delay(RELAY_DURATION);
    pinMode(PCH4, INPUT);
    pinMode(NCH4, INPUT);
    delay(1);
}


// Primary functions:

int get_next_random_mapping() {
    int new_mapping;
    // use up to 100 numbers from each seed.
    if (g_random_seq >= 100) {
        g_random_seed++;
        g_random_seq = 0;
    }
    randomSeed(g_random_seed);
    // skip over the previously used numbers from this seed.
    for (int skip=0; skip < g_random_seq; skip++) {
        new_mapping = random(MAPPING_A_IS_X, MAPPING_A_IS_Y+1);
    }
    new_mapping = random(MAPPING_A_IS_X, MAPPING_A_IS_Y+1);
    g_random_seq++;
    return new_mapping;
}

void do_reroll() {
    g_abxy_mapping = get_next_random_mapping();

    bool should_toggle_odd;
    if (g_abxy_mapping == MAPPING_A_IS_X && g_input_position == POSITION_X) {
        should_toggle_odd = false;
    } else if (g_abxy_mapping == MAPPING_A_IS_X && g_input_position == POSITION_Y) {
        should_toggle_odd = true;
    } else if (g_abxy_mapping == MAPPING_B_IS_X && g_input_position == POSITION_X) {
        should_toggle_odd = true;
    } else if (g_abxy_mapping == MAPPING_B_IS_X && g_input_position == POSITION_Y) {
        should_toggle_odd = false;
    } else {
        panic();
    }

    disconnect_output_relays();

    if (should_toggle_odd) {
        toggle_dummy_relays();
        toggle_input_relays();
        toggle_dummy_relays();
    } else {
        toggle_input_relays();
        toggle_dummy_relays();
        toggle_input_relays();
    }

    store_globals_in_eeprom();

    connect_output_relays();

    while (true) {
        turn_on_LED(LED_A);
    }
}

void do_reveal() {
    while (true) {
        if (g_input_position == POSITION_X && g_abxy_mapping == MAPPING_A_IS_X) {
            turn_on_LED(LED_X);
            turn_on_LED(LED_A);
        } else if (g_input_position == POSITION_X && g_abxy_mapping == MAPPING_B_IS_X) {
            turn_on_LED(LED_X);
            turn_on_LED(LED_B);
        } else if (g_input_position == POSITION_Y && g_abxy_mapping == MAPPING_A_IS_Y) {
            turn_on_LED(LED_Y);
            turn_on_LED(LED_A);
        } else if (g_input_position == POSITION_Y && g_abxy_mapping == MAPPING_B_IS_Y) {
            turn_on_LED(LED_Y);
            turn_on_LED(LED_B);
        } else {
            panic();
        }
    }
}

void do_switch() {
    disconnect_output_relays();

    if (g_input_position == POSITION_X) {
        set_input_relays_to_y();
    } else if (g_input_position == POSITION_Y) {
        set_input_relays_to_x();
    } else {
        panic();
    }

    store_globals_in_eeprom();

    connect_output_relays();

    while (true) {
        if (g_input_position == POSITION_X && g_abxy_mapping == MAPPING_A_IS_X) {
            turn_on_LED(LED_A);
        } else if (g_input_position == POSITION_X && g_abxy_mapping == MAPPING_B_IS_X) {
            turn_on_LED(LED_B);
        } else if (g_input_position == POSITION_Y && g_abxy_mapping == MAPPING_A_IS_X) {
            turn_on_LED(LED_B);
        } else if (g_input_position == POSITION_Y && g_abxy_mapping == MAPPING_B_IS_X) {
            turn_on_LED(LED_A);
        } else {
            panic();
        }
    }
}


// Arduino functions:

void setup() {
    // Wait long enough to get past any initial switch bouncing.
    delay(1);

    load_globals_from_eeprom();

    if (digitalRead(MODE_PIN_REROLL)) {
        do_reroll();
    } else if (digitalRead(MODE_PIN_REVEAL)) {
        do_reveal();
    } else if (digitalRead(MODE_PIN_SWITCH)) {
        do_switch();
    } else {
        panic();
    }
}

void loop() {

}

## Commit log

2020-10-31 initial commit (v2)
    [abx-B_Cu.gbl, abx-B_Mask.gbs, abx-B_SilkS.gbo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]
2020-10-31 v2 board shots
2020-10-31 photo of v1 assembled board
2020-11-01 board revision 3
    [abx-B_Cu.gbl, abx-B_Mask.gbs, abx-B_SilkS.gbo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]
2020-11-01 v3 board shots
2020-11-04 v4 board shots
2020-11-17 v4.1 (bugfix)
    [abx-B_Cu.gbl, abx-B_Mask.gbs, abx-B_SilkS.gbo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]
2020-11-17 silkscreen fix
    [abx.kicad_pcb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]
2020-11-17 board shots v4.1
